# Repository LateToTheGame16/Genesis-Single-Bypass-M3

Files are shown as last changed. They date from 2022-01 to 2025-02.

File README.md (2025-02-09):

# Sega Genesis Model 3 Stereo Mod
Restore stereo audio on a Sega Model 3. Only three wires to solder. Composite video still works! Only usable on a Model 3 Genesis.
This is a redesign of the fantastic 3bp from dbElectronics and Tian Feng. The goal of this project was to minimize wires to only do the audio bypass.
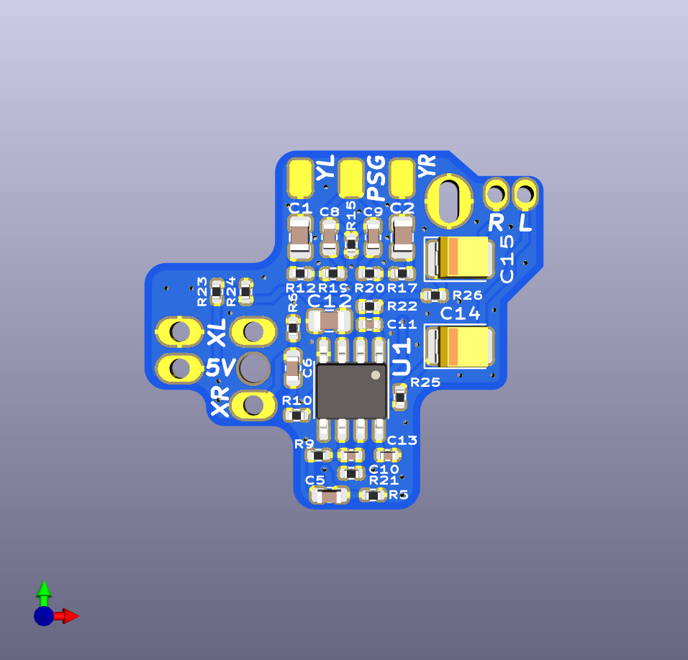
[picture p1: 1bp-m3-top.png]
top_screenshot
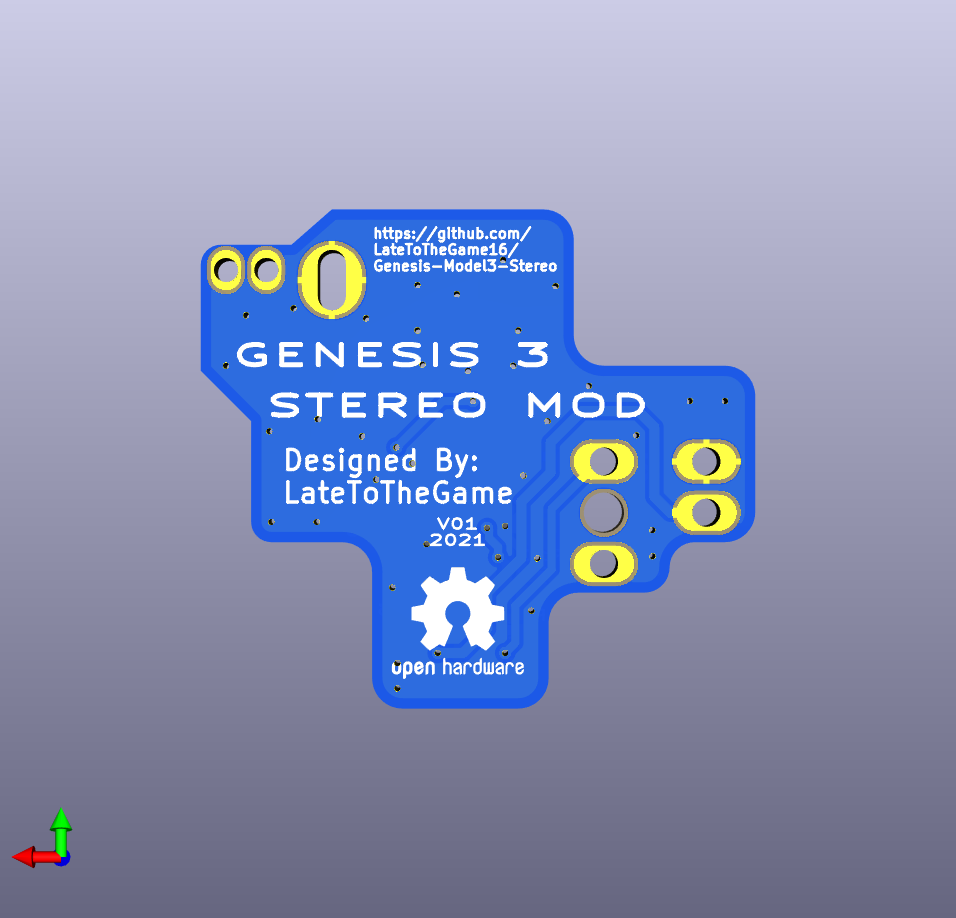
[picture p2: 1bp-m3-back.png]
back_screenshot
 

# Installation Instructions
Currently I suggest using the Audio installation instructions from https://github.com/zaxour/TripleBypassV2Plus
The 32X audio is taken from the cart connector. The audio is output to the Genesis Mini-DIN.
Solder wires for Audio Left, Audio Right, PSG taken from the top side of the Genesis motherboard.
# Design Files
The designs are done with Kicad 6.0. The designs were done from scratch and are native to Kicad. 
The schematic uses the same values as https://github.com/tianfeng33/triple-bypass-Version-2. 
The mechanicals changed to ease installation. 
# Change Log from V2
  - Schematics and Layout redrawn from scratch in Kicad. 
  - Only three wires need to be soldered. Video signals are not touched.

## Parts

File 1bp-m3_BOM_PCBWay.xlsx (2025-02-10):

 |  |  | xxxx xxxx xxxxx xxPCS BOM (Sample Bill of Materials)
Item # | *Designator | *Qty | Manufacturer | *Mfg Part # | Description / Value | *Package/Footprint | Type | Your Instructions / Notes
1 | U1 | 1 | Linear | LTC3780EG#PBF | IC BUCK-BOOST CONV 24-SSOP | 24-SSOP | SMD
2 | U2,U4 | 2 | Fairchild | LM2904M | IC OPAMP DUAL -40-85 C 8-SOIC | 8-SOIC | DNS
3 | U3 | 1 | ON | LM317MBDTG | LM317M IC REG VOLT ADJ 500MA DPAK | DPAK | SMD
4 | U5 | 1 | Microchip | PIC16F690-I/SS | IC PIC MCU FLASH 4KX14 20SSOP | 20SSOP | SMD
5 | Q1 | 1 | Diodes Inc | GBJ10005-F | RECT BRIDGE GPP 50V 10A GBJ | GBJ | SMD
6 | R14,R18 | 2 | Panasonic | ERJ-6ENF4701V | RES 4.70K OHM 1/8W 1% 0805 SMD | 0805 | SMD
7 | R15 | 1 | Susumu | RL3720WT-R022-F | RES .022 OHM 1W 1% 0815 SMD | 0815 | SMD
8 | R16, R31 | 2 | Panasonic | ERJ-6ENF4702V | RES 47.0K OHM 1/8W 1% 0805 SMD | 0805 | SMD
9 | C5 | 1 | Murata | GRM21BR71C225KA12L | CAP CER 2.2UF 16V X7R 0805 | 0805 | SMD
10 | C7 | 1 | Murata | GRM21BR71C475KA73L | CAP CER 4.7UF 16V X7R 0805 | 0805 | DNS
11 | C8,C22 | 2 | Muruta | GRM21BR71C105KA01L | CAP CER 1.0UF 16V 10% X7R 0805 | 0805 | SMD
12 | CN6 | 1 | Molex | 538-53398-0671 | 1.25mm Connectors VERTICAL HDR SMT 6P | SMT 6P | SMD
13 | L1,L2 | 2 | Coiltronics | DR127-150-R | INDUCTOR SHIELD PWR 15UH SMD | SMD | SMD
14 | L3 | 1 | TDK | ACM1211-102-2PL-TL | CHOKE COMM MODE 1000 OHM 6A SM | SMD | SMD
15 | CN3,CN4 | 2 | Molex | 53047-0510 | CONN HEADER 5POS 1.25MM VERT TIN | 5POS | thru-hole
Need a quick and accurante quote? Need an efficient production? Please read SMT Ordering Necessary Files & Info in 1 minute. Thank you very much! (https://www.pcbway.com/smt_ordering_guide.html)
Click for Instructions on How to Create a BOM (https://www.pcbway.com/blog/PCB_Assembly/How_to_Build_a_BOM__Bill_Of_Materials_.html)

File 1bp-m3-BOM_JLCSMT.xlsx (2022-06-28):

Comment | Designator | Footprint | JLCPCB Part #（optional）
10uF | C1, C2, C12 | Capacitor_SMD:C_0805_2012Metric | C15850
1uF | C5, C6, C8, C9 | Capacitor_SMD:C_0603_1608Metric | C29936
150pF | C10, C11 | Capacitor_SMD:C_0402_1005Metric | C76951
0.1uF | C13 | Capacitor_SMD:C_0402_1005Metric | C1525
47uF | C14, C15 | Capacitor_Tantalum_SMD:CP_EIA-3528-21_Kemet-B | C22036
75R | R5, R6 | Resistor_SMD:R_0402_1005Metric | C25133
210K | R9, R10, R19, R20 | Resistor_SMD:R_0402_1005Metric | C58827
130K | R12, R17 | Resistor_SMD:R_0402_1005Metric | C52929
2K2 | R15 | Resistor_SMD:R_0402_1005Metric | C25879
300K | R21, R22 | Resistor_SMD:R_0402_1005Metric | C25774
10K | R23, R24 | Resistor_SMD:R_0402_1005Metric | C25744
330R | R25, R26 | Resistor_SMD:R_0402_1005Metric | C25102
TL972IDR | U1 | Package_SO:SOIC-8_3.9x4.9mm_P1.27mm | C46127

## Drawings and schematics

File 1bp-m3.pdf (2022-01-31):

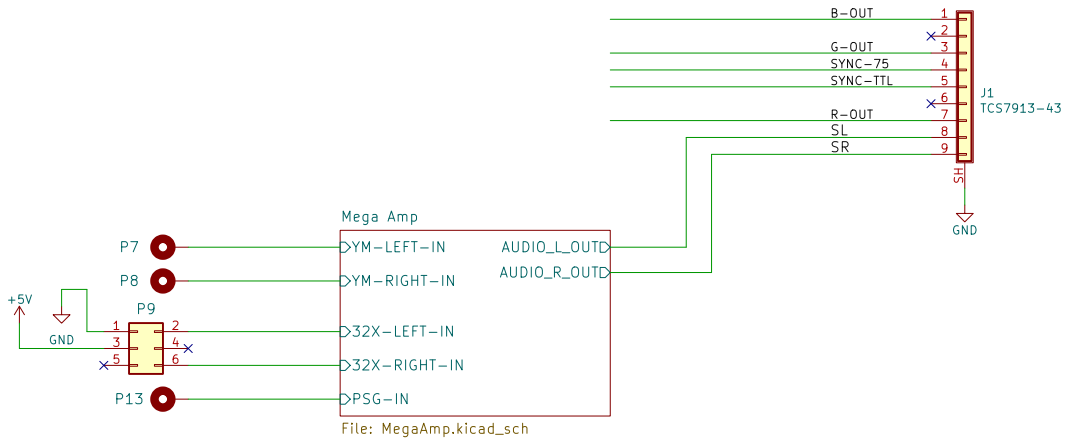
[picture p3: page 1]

R-OUT SYNC-TTL SLG-OUT SYNC-75 B-OUT

Licensed under CERN OHL v.1.2 For Genesis 3 consoles only

https://github.com/LateToTheGame16/Genesis-Model3-Stereo
File: 1bp-m3.kicad_sch Sheet: / Late to the Game

Id: 1/2 Title: Genesis Model 3 Stereo Audio

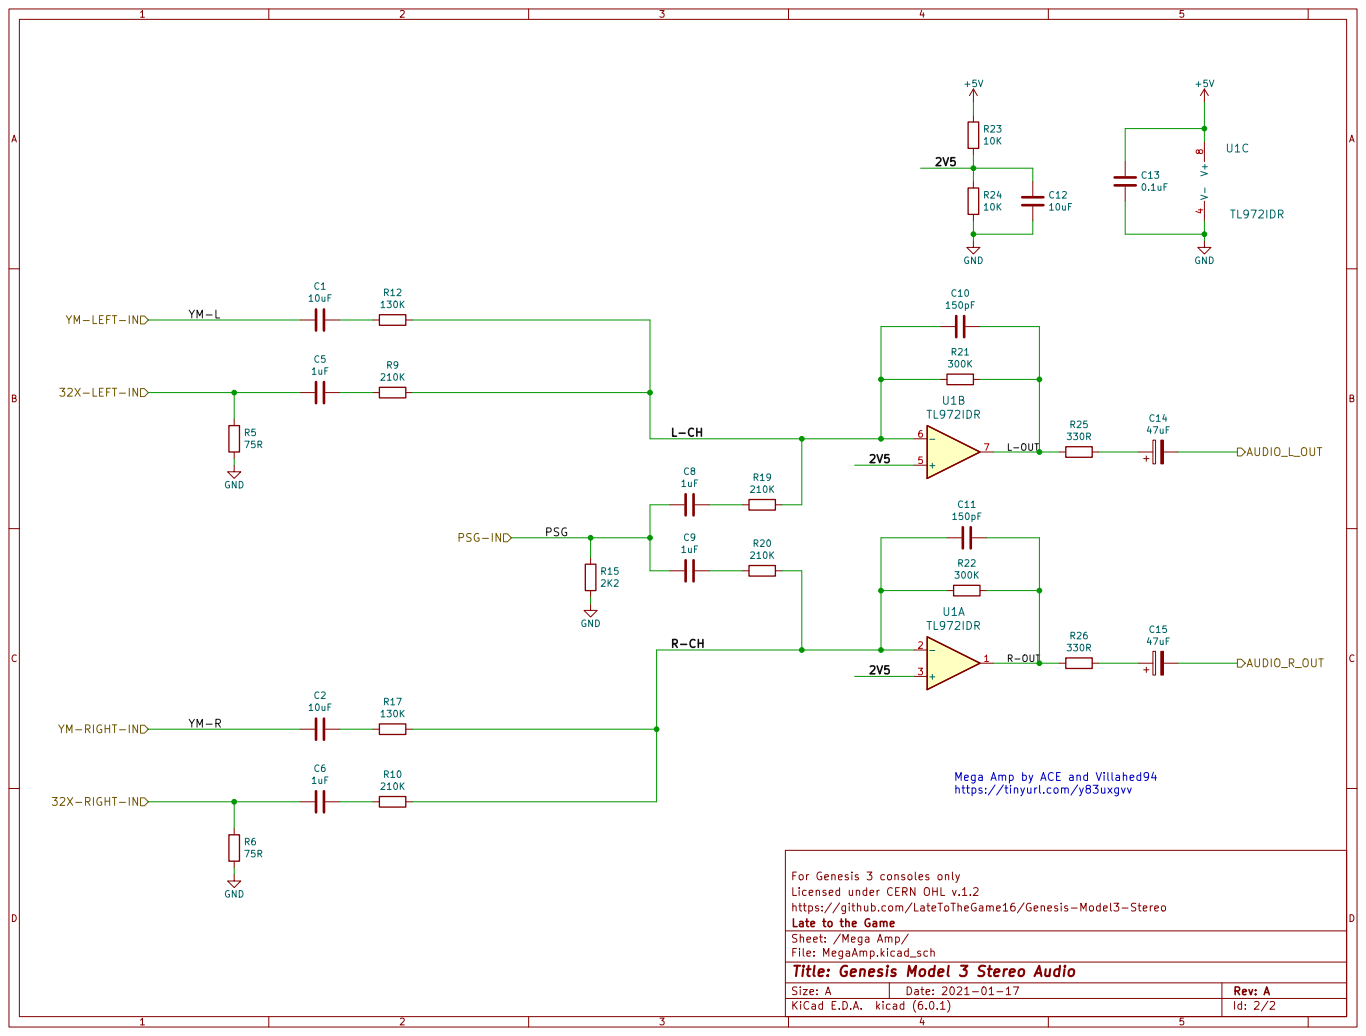
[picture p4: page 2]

Licensed under CERN OHL v.1.2 For Genesis 3 consoles only R19

https://github.com/LateToTheGame16/Genesis-Model3-Stereo
Sheet: /Mega Amp/ Late to the Game

File: MegaAmp.kicad_sch
Id: 2/2 Title: Genesis Model 3 Stereo Audio

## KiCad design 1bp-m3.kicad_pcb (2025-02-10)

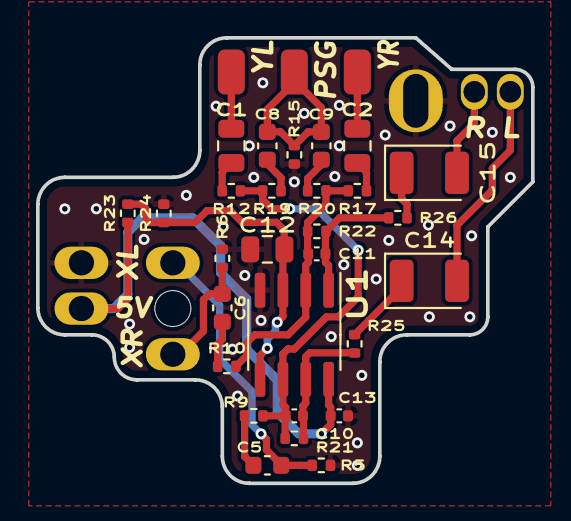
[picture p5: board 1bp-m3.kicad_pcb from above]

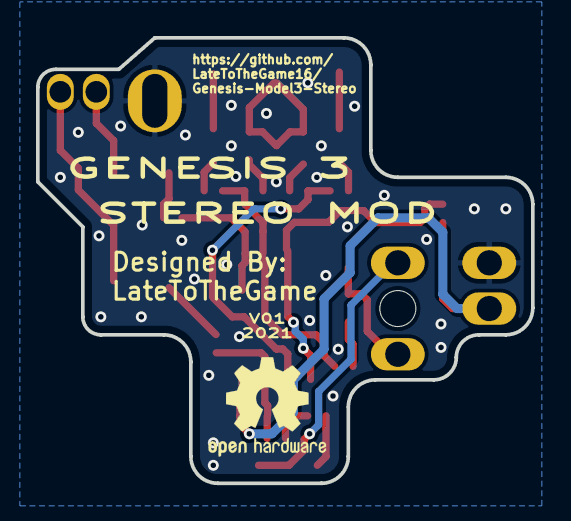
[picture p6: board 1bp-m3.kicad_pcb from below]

Board: 2 copper layers, 27.5 x 24.8 mm, 34 parts (2 on the bottom side), 22 nets.

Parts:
C1, C2, C12: 10uF; C_0805_2012Metric
C5, C6, C8, C9: 1uF; C_0603_1608Metric
C10, C11: 150pF; C_0402_1005Metric
C13: 0.1uF; C_0402_1005Metric
C14, C15: 47uF; CP_EIA-3528-21_Kemet-B
J1: TCS7913-43; MiniDIN_TCS7913-43
LOGO1: Logo_Open_Hardware_Small; OSHW-Logo2_7.3x6mm_SilkScreen
P7, P8, P13: TP_50; TestPoint_Pad_1.5x1.5mm
P9: TP_50; PinHeader_2x03_P2.54mm_Vertical
R5, R6: 75R; R_0402_1005Metric
R9, R10, R19, R20: 210K; R_0402_1005Metric
R12, R17: 130K; R_0402_1005Metric
R15: 2K2; R_0402_1005Metric
R21, R22: 300K; R_0402_1005Metric
R23, R24: 10K; R_0402_1005Metric
R25, R26: 330R; R_0402_1005Metric
U1: TL972IDR; SOIC-8_3.9x4.9mm_P1.27mm

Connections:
+5V: C13.1, P9.3, R23.1, U1.8 (V+)
/Mega Amp/2V5: C12.2, R23.2, R24.1, U1.3 (+), U1.5 (+)
/Mega Amp/32X-LEFT-IN: C5.1, P9.2, R5.1
/Mega Amp/32X-RIGHT-IN: C6.1, P9.6, R6.1
/Mega Amp/L-CH: C10.1, R9.2, R12.1, R19.2, R21.1, U1.6 (-)
/Mega Amp/L-OUT: C10.2, R21.2, R25.1, U1.7
/Mega Amp/PSG: C8.1, C9.1, P13.1, R15.1
/Mega Amp/R-CH: C11.1, R10.2, R17.1, R20.2, R22.1, U1.2 (-)
/Mega Amp/R-OUT: C11.2, R22.2, R26.1, U1.1
/Mega Amp/YM-L: C1.1, P7.1
/Mega Amp/YM-R: C2.1, P8.1
/SL: C14.2, J1.8
/SR: C15.2, J1.9
GND: C12.1, C13.2, J1.SH (Shield), P9.1, R5.2, R6.2, R15.2, R24.2, U1.4 (V-)
unnamed: C1.2, R12.2
unnamed: C2.2, R17.2
unnamed: C5.2, R9.1
unnamed: C6.2, R10.1
unnamed: C8.2, R19.1
unnamed: C9.2, R20.1
unnamed: C14.1, R25.2
unnamed: C15.1, R26.2

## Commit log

2022-01-27 initial upload
    [1bp-m3.kicad_pcb, 1bp-m3.kicad_sch, MegaAmp.kicad_sch]
2022-01-31 updated silkscreen for OSHW
    [1bp-m3.kicad_pcb, 1bp-m3.kicad_sch, MegaAmp.kicad_sch]
2022-06-28 export gerbers
    first fab run
    [1bp-m3-B_Cu.gbr, 1bp-m3-B_Mask.gbr, 1bp-m3-B_Silkscreen.gbr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]
2022-06-28 built by JLCPCB
    first build attempt
    [1bp-m3-BOM_JLCSMT.xlsx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]
2025-02-09 Update README.md
    Deleted parts saying the board was untested. It has been tested and works.
    Added a link to zaxour github page because he has great installation guides.
2025-02-10 Saved in KiCad 8.0, fixed part descriptions
    Component descriptions were wrong. Parts said 0603 but were really a 0402 footprint. No real changes to schematic or pcb. Saving from KiCad 6 to KiCad 8 created lots of format changes.
    [1bp-m3.kicad_pcb, 1bp-m3.kicad_sch, 1bp-m3_BOM_PCBWay.xlsx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]
